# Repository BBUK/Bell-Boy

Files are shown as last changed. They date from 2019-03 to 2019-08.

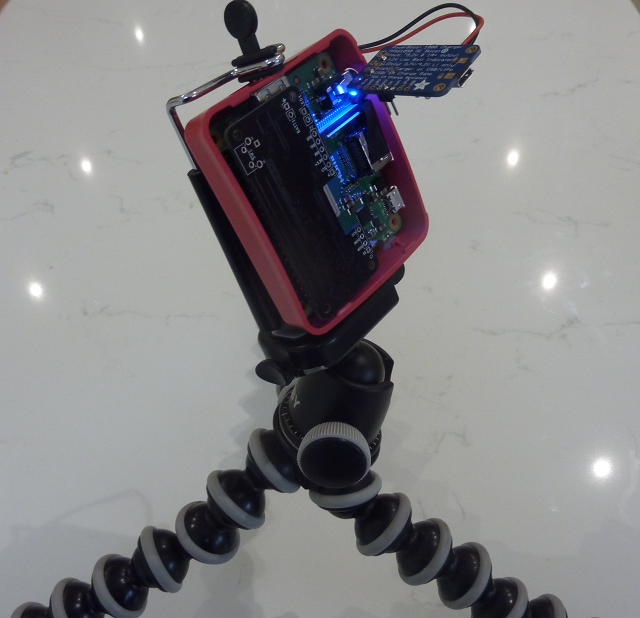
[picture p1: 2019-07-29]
images/CalibrationDevice.png

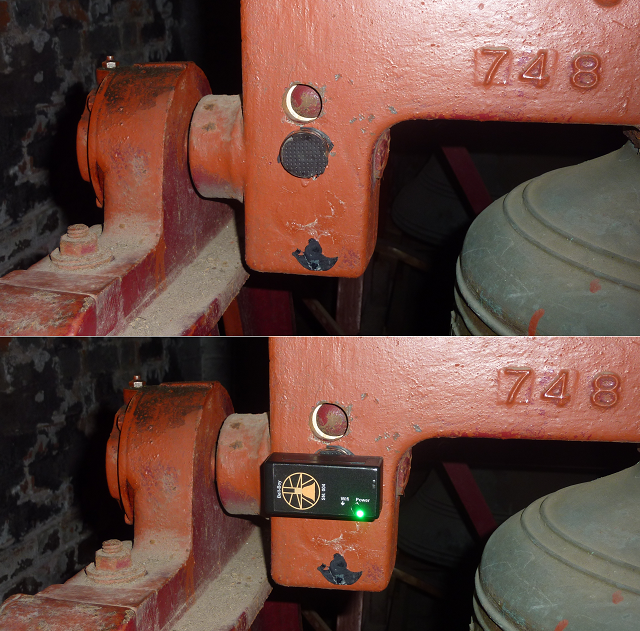
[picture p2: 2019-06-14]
images/Mounting.png

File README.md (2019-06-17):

# Bell-Boy
NEW VERSION IMMINENT - THIS REPOSITORY CONTAINS A GREAT DEAL OF CODE AND INFORMATION IN FLUX BETWEEN VERSIONS SO SHOULD NOT BE RELIED UPON

This repository contains the code and hardware design for the Bell-Boy Project.  

The Bell-Boy is a device used to measure how hard a person pulls on a tower bell rope.  I hope it will be a useful training aid.  

## Hardware

The core of the hardware comprises a Raspberry Pi Zero and a PCB mounted on it containing an IMU IC (an ICM20689), a ATMEGA328 with the Arduino bootloader and power management and battery charging circuitry.  The Arduino manages battery charging, controls a LED and also stores device calibration data.  The battery is a LiPo integral to the device and is charged via power sourced from the Rasperry Pi's micro USB power socket.  The wiki gives construction information if you want to build your own.

The various files and a description of what they do is set out below

This is the second version of the hardware.  The first version was designed to be mounted on top of the headstock.  More accurate measurements were found to have been achieved by mounting the device closer to the gudgeon pins of the bell.  That required the device to be smaller, which required a LiPo battery. As I could not find a case that would fit a Pi0 and one of the AA sized LiPo batteries, a "flat" LiPo was used which then needed associated charging paraphernalia.

Despite only using one consumer-grade IMU, the second version is *much* more accurate than the first.  There is virtually zero drift in angular readings for all three axes (less than 0.3 degrees per hour).  Acceleration measurements are similarly improved.

## Software

### setupBB.sh

This script takes a stock installation of Arch Linux Arm (for the Raspberry Pi) and adds all scripts and installs all required packages to set up the software environment.  See the wiki for more details 

### grabber

This folder contains the source for two small executables.  

The first, "grabber" takes data from the IMU, transforms it into angle, rotational velocity and rotational acceleration and pushes the data to the users browser via a websocket.  As the force applied by the ringer on the rope needs to be distinguished from gravity, vibration and sensor noise, the solution:

(a) oversamples data from the IMUs (sensors output at 500Hz but the user sees 125Hz).

(b) uses a straightforward Mahony-type filter to calculate angles (I previously used the extended Kalman filter (from https://github.com/hhyyti/dcm-imu) to calculate bell angle but it produced no better results in this application).

(c) uses a Savitsky-Golay filter to smooth the measured rotational acceleration

(d) requires an one-time calibration of the IMU system (from https://bitbucket.org/alberto_pretto/imu_tk).  This is a really useful method of scale and bias calibration that does not require the IMU to be exactly positioned.

The grabber communicates with the user's broswer via websocketd (https://github.com/joewalnes/websocketd). 

The second executable "powermonitor" monitors battery level reports from the Arduino and shuts down the Pi if he battery is too low.  It only operates when the grabber is not running (the grabber only runs when there is an active websocket connection to the user's browser - if there is such a connection, the grabber takes over power monitoring).

### bellboy.js

The Javascript that takes the data from the Bell-Boy and presents it to the users browser.  The browser must support HTML5 and websockets.  More details for operation are in the wiki.

### index.html

Index file.  Note that this file and the JS reference certain image files (icons used to control the front end).  These were licensed in my me but whilst I am permitted to include them on websites that I operate or in code that I distribute, I am not permitted to make them available in a separately downloadable form.

### help.html

Help html file served by the Bell-Boy device.

### utility

Some useful utility programs and files.  There is some information here on installing imu_tk (and in particular ceres-solver which is used by imu_tk).

### arduino

Contains the Arduino program running on the "Arduino'd" ATMEGA328 on the Bell-Boy PCB

### old 

Contains some old code and in particular some code for BNO080 interfacing over the Raspberry Pi's SPI which some people may find useful.  I am no longer using the BNO080 so don't expect this code to be updated.

# Donations!
[Donations](https://paypal.me/PBUK) to this project are welcome :)

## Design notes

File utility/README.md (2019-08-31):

## Calibration

Two methods of calibration are provided.  The first uses imu_tk and provides more calibration data (but is difficult to set up) and the second is simpler and can be more easily run on the Bell-Boy itself.

### imu-tk
To calibrate the ICM20689, imu_tk needs to be installed.  imu_tk needs Ceres Solver to be installed.  Ceres Solver only just compiles on the 500MB Pi (better on the larger-memoried models).  Step by step instructions on how to install Ceres Solver and imu_tk are in the NotesOnInstallingimu_tk.txt file.  Other files used are ICM20689.h, BBimu_tk.cpp (a slight variation of the sample file provided as part of imu_tk), calibrate.c and getcalibration.c (the latter is not necessary for doing the calibration but is a handy way of seeing the calibration loaded).

### 6-position
This is in calibrate-6.c.  It is a reasonbly standard 6-position IMU calibration program for 6-DOF IMUs.  This is of the type that uses Gaussian elimination so does not require exact positioning on each of the six faces (within 10 degrees will be fine).  Compile it, run it and as for the imu_tk version, enter SAMP: a few times until you see stable numbers, then enter CALI: to start the calibration process (and follow the on-screen instructions).  Once done, enter SAVE: to save the calibration data to the Bell-Boy.  This program produces good results (pretty much indisguishable from imu_tk in real use) but does not calibrate for gyro scale or axis misalignment errors (which imu_tk does).

## g calculator

gcalculator.xlsx is a little spreadsheet I used to work out what g is in my viscinity.  I am sure the variance in g is not enough to make much difference to results.

## Battery

batteryrecord.txt and BatteryCalibration.xlsx are files file showing how battery voltage is reported over time.  As LiPo batteries discharge on a curve, I could use this data to work out how much battery time is remaining.

## Logo

Bell2LogoSheet.docx is just a Word file with the Bell-Boy logo printed on it (ready to go onto a sticker sheet).

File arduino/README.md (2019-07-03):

## bellboy

This contains an Arduino-style sketch that runs on the ATmega on the Bell-Boy PCB.  The LowPower library is required. 

## BBCalib

A little Arduino sketch that moves servos on my auto calibration deck.

## HotPlate

An Arduino sketch that controls my homebrew soldering hot plate.  It uses a DOGM LCD I had lying around and the PID library.

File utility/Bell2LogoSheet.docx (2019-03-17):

Bell-Boy SN: 001 | UP → | Bell-Boy SN: 002 | UP → | Bell-Boy SN: 003 | UP →
| Wifi Power | | Wifi Power | | Wifi Power
Bell-Boy SN: 004 | UP → | Bell-Boy SN: 005 | UP → | Bell-Boy SN: 006 | UP →
| Wifi Power | | Wifi Power | | Wifi Power
Bell-Boy SN: 007 | UP → | Bell-Boy SN: 008 | UP → | Bell-Boy SN: 009 | UP →
| Wifi Power | | Wifi Power | | Wifi Power
Bell-Boy SN: 010 | UP → | Bell-Boy SN: 011 | UP → | Bell-Boy SN: 012 | UP →
| Wifi Power | | Wifi Power | | Wifi Power
Bell-Boy SN: 013 | UP → | Bell-Boy SN: 014 | UP → | Bell-Boy SN: 015 | UP →
| Wifi Power | | Wifi Power | | Wifi Power
Bell-Boy SN: 016 | UP → | Bell-Boy SN: 017 | UP → | Bell-Boy SN: 018 | UP →
| Wifi Power | | Wifi Power | | Wifi Power
Bell-Boy SN: 019 | UP → | Bell-Boy SN: 020 | UP → | Bell-Boy SN: 021 | UP →
| Wifi Power | | Wifi Power | | Wifi Power
Bell-Boy SN: 022 | UP → | Bell-Boy SN: 023 | UP → | Bell-Boy SN: 024 | UP →
| Wifi Power | | Wifi Power | | Wifi Power
Bell-Boy SN: 025 | UP → | Bell-Boy SN: 026 | UP → | Bell-Boy SN: 027 | UP →
| Wifi Power | | Wifi Power | | Wifi Power

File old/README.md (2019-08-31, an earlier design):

## Here is some old code preserved in case someone finds it useful

### kalman.h

This is a pretty good general Kalman filter for use with 6DOF data.  It produces good results but on testing was not any better than the Mahony filter used as part of the grabber.  It is based on https://github.com/memsindustrygroup/Open-Source-Sensor-Fusion.  It's good for me because it is pure C and does not use anything other than the standard libraries.  Instructions for compilation and use are in the file.

### BNO080grabber.c and BNO080-general.c

I experimented for a bit with the BNO080 devices.  These produced good pose quaternions but tended to recalibrate themselves at inopportune moments.  The two files here are the specific driver for the Bell-Boy grabber and a more general one.

### Other files

Will not be of much use to anyone, except, perhaps the dual MPU6050 code (which I used when the Bell-Boy had two IMU ICs working in parallel.  It demonstrates how I aligned the FIFO outputs from the two ICs.

The 32kHz.c file shows how to create a 32768Hz (ish) clock from the Pi's PWM hardware.  This clock was used for the BNO080s (to save the hardware needing a crystal and a couple of caps).

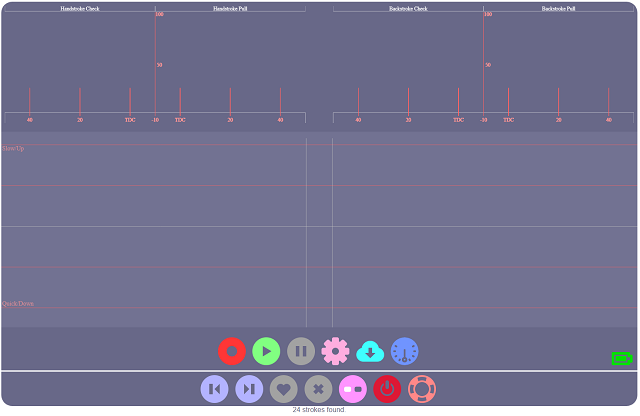
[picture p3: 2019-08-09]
images/FileLoaded.png

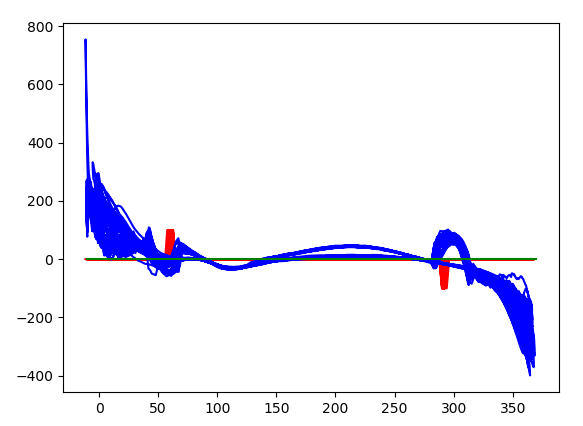
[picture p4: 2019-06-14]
images/OtherEffects2.png

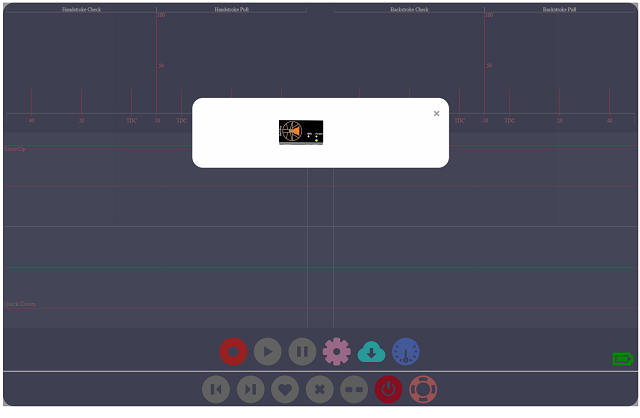
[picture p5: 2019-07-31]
images/EyeCandy.png

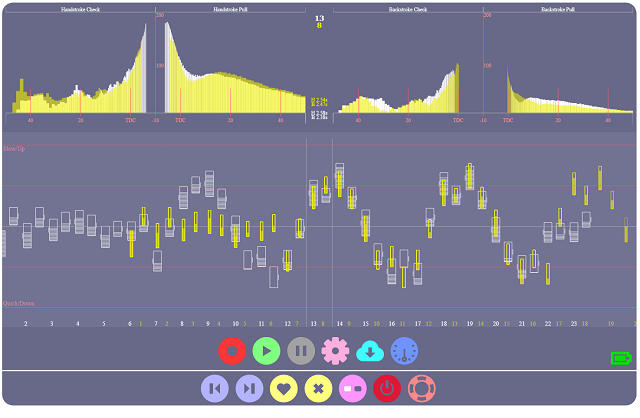
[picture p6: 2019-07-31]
images/StrokeComparison.png

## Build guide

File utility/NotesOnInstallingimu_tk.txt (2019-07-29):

Start with Raspbian full standard installation

sudo apt-get update
sudo apt-get upgrade
sync && sudo reboot
sudo apt-get install build-essential cmake libeigen3-dev libqt4-dev libqt4-opengl-dev freeglut3-dev gnuplot libxmu-dev libxi-dev libgoogle-glog-dev libatlas-base-dev libsuitesparse-dev libboost-dev screen cmake-curses-gui
wget http://ceres-solver.org/ceres-solver-1.14.0.tar.gz
tar xzvf ceres-solver-1.14.0.tar.gz
nano /etc/dphys-swapfile
#change swapfile size to 500. Probably overkill but leave it like this after installation as memory usage for actual calibration runs is huge
sudo systemctl restart dphys-swapfile
mkdir ceres-bin
cd ceres-bin
ccmake ../ceres-solver-1.14.0
# configure
# set build testing to no
# set build examples to no
# configure
# generate
make
#(make will take a long while)
sudo make install

wget https://bitbucket.org/alberto_pretto/imu_tk/get/7780270fb9a2.zip -O imu_tk.zip
unzip imu_tk.zip
cd alberto_pretto-imu_tk-7780270fb9a2/
nano CMakeLists.txt
# add this to the examples section of the file (towards the bottom) (without the hashes)
# add_executable(BBimu_tk apps/BBimu_tk.cpp)
# target_link_libraries( BBimu_tk ${IMU_TK_LIBS})
# set_target_properties( BBimu_tk PROPERTIES RUNTIME_OUTPUT_DIRECTORY ${PROJECT_SOURCE_DIR}/bin)

#copy the BBimu_tk.cpp file to alberto_pretto-imu_tk-7780270fb9a2/apps directory
mkdir build
cd build
cmake ..
### if using gcc version > 6 (eg on Buster), install gcc-6 and g++-6 and run cmake something like this 'cmake -D CMAKE_C_COMPILER="/usr/bin/gcc-6" -D CMAKE_CXX_COMPILER="/usr/bin/g++-6" ..'
make

#install bcm2835 library - see setupBB.sh
#compile calibrate.c needs ICM20689.h
gcc calibrate.c -o calibrate -lbcm2835
# put BBimu_tk (in alberto_pretto-imu_tk-7780270fb9a2/bin) into same directory as calibrate program
# shutdown

## to do a calibration run
# with bellboy PCB installed on header of Pi
# power on system - best to run this after a reboot
# can use battery power if this is running on a zero, if not, power Pi separately and remove battery from bellboy PCB
# run calibrate
# enter SAMP: to get sample period a few times - check numbers are sane and stable (on multiple entries) - near to 0.002 for sample period
# enter CALI: to start calibration run
# keep device stable for at least 50 secs and then move into 20-30 different positions each stable for at least 3-4 seconds(ish)
# ensure that there is a full range of positions (important)
# if EOVF: appears then ctrl-c to exit, reboot and try again
# enter STCA:
# (will now run imu_tk calibration)
# ???high residuals (>2) are an indication that something is not right 
# OK for EOVF: to appear after calibration is finished
# enter SAVE:
# check numbers are sane:
    # all bias numbers close to 0
    # all transform numbers close to 1 on diagonal and close to zero otherwise
# if not sane - ctrl-c to exit within 20 secs. Reboot and try again
# if ctrl-c is not entered, calibration is saved to arduino on bellboy device automatically

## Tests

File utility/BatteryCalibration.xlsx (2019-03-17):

drop: | 0.32
reading: | 447 | voltage: | 4.099865772
 | 459 |  | 4.001045752
 |  |  | #DIV/0!
 |  |  | #DIV/0!
 | 492 |  | 3.754146341
 | 495 |  | 3.733333333
 |  |  | #DIV/0!
 | 498 |  | 3.712771084 | 3.72
 |  |  | #DIV/0!
 |  |  | #DIV/0!
 |  |  | #DIV/0!
 |  |  | #DIV/0!
 |  |  | #DIV/0!
 | 500 |  | 3.6992
 | 506 |  | 3.659130435
 | 509 |  | 3.639449902
 | 511 |  | 3.626457926 | 3.6
 |  |  | #DIV/0!
 |  |  | #DIV/0!
 |  |  | #DIV/0!
 |  |  | #DIV/0!
 |  |  | #DIV/0!
 |  |  | #DIV/0!
 |  |  | #DIV/0!
 |  |  | #DIV/0!
 |  |  | #DIV/0!
 |  |  | #DIV/0!
 |  |  | #DIV/0!
 |  |  | #DIV/0!
 |  |  | #DIV/0!
 |  |  | #DIV/0!
 |  |  | #DIV/0!
 |  |  | #DIV/0!
 | 541 |  | 3.44310536

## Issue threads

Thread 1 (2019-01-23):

BNO080-general.c does not work on my RPi 3B+

tbrych, 2019-01-23:
Hey @BBUK!

I downloaded your code and copied it on my RPi 3B+, after that I installed the BCM2835 lib and compiled your code.
When executing, I get the error "Unsolicited packet not received\n". What does does it mean, that the unsolicited packet wasn't received. This error-message doesn't make any sense to me.
What can I do against it?

The pins connected on the BNO080 are:
PS1 ->   3.3V
GND ->   GND
VDD ->   3.3V
SCK ->   BCM11
SO  ->   BCM9
SI  ->   BCM10
CS  ->   BCM8
WAK ->   BCM25
RST ->   BCM24
INT ->   BCM23

Thank you!
tbrych

BBUK, 2019-01-24:
Hi tbrych.
On reset the BNO080 (should) send a reset packet followed by a long (over 250 byte) unsolicited capability advertisement packet.  The code is complaining that it not seeing the unsolicited packet.  The wiring looks OK,  What BNO080 board are you using?
BBUK

tbrych, 2019-01-25:
We use a Sparkfun BNO080 (https://www.sparkfun.com/products/14686)

BBUK, 2019-01-30:
@tbrych
Weird one.  Worked fine in Arch (which I use).  Tried it in Raspbian (which I assume you are using) and had the same error.

Turned out that the initialisation code did not wait long enough for the unsolicited packet.  I have now pushed a fix but you can just increase the usleep in line 821 from 5000 to 10000.

Thanks for the bug report!  Please report back if this is fixed from your end and I'll close the issue.

tbrych, 2019-02-03:
@BBUK
Thanks for the help, it worked on my side! 👍

BBUK, 2019-02-03:
Thanks for the feedback.  Note that I have just changed the fix slightly to make it more robust.

Closed 2019-02-03.

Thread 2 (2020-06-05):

Issue with BNO080

CalebVaccaro, 2020-06-05:
We are having trouble connecting the I2C with the rPI. We need help with reading data from the sensor from the I2C. Can we pm you?

BBUK, 2020-06-05:
The BNO080 needs I2C clock stretching which the Pi does not do so well.  See here: [https://www.raspberrypi.org/forums/viewtopic.php?t=234577](url) .  This is why I used SPI.  I wonder if this is the problem you are experiencing...

CalebVaccaro, 2020-06-05:
The link is not working. Do you think its still a viable option to use the Pi. We just need quats off the sensor. If not, have you worked with better options for IMUs (components that could accomplish the same goal). Thanks for the reply

Would you know of an SPL library for it?

Parts List:
Qwiic VR IMU (BNO080)
Qwiic pHAT v2.0
Rasberry pi 4

BBUK, 2020-06-05:
Sorry, try this [link](https://www.raspberrypi.org/forums/viewtopic.php?t=234577).  I don't know for sure but I think the Qwiic connectors only use I2C.  I also don't know if the Pi I2C clock stretching bug is still there in the Pi4.

If I2C is a problem then that board can use SPI, you just need to wire the Pi to the SPI pins.  See [issue 1](https://github.com/BBUK/Bell-Boy/issues/1), to see someone who did just that with the same board with success using the code here.

Closed 2020-08-12.

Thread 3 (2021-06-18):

RST in old BNO080-general.c

mdgc3, 2021-06-18:
Good afternoon,
I am fairly new at mechatronics and am working to use SPI with a BNO080. I thought I followed your instructions correctly (yes I tried to make sure I plugged in the correct pins since they are BCM pins), but it keeps getting stuck on "device did not wake on reset". I do not know if it is a wiring issue or because I have a Raspberry Pi 4B and you were using a Raspberry Pi Zero, or if something else is going on. I have attached photos and would really really appreciate some help.
[edit- I saw in your past issues you had a similar question. My wiring is the same I think, but I changed the usleep in line 819 to 10000 just in case. I have also tried plugging in the RST wire on both of the options on the BNO080 from sparkfun]

Below is my wiring: (sorry about color repeats I didn't have a ton of wires)
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

Thank you for your patience,
mdgc3

mdgc3, 2021-07-07:
I seem to have gotten it to work once, but then I upgraded my raspberry pi on the command line and it does not work again.

Also what is a continuation????

BBUK, 2021-07-07:
I see you still have the pull-up resistors connected.  They are only used for i2c.  According to this: https://cdn.sparkfun.com/assets/5/c/c/8/8/SparkFun_Qwiic_VR_IMU_Breakout.pdf the jumper should be cleared (both sides) for SPI usage.  Also, have you set PS0 and PS1 correctly?

mdgc3, 2021-07-07:
I saw you talked about that and eventually cleared the jumper (you mean desoldering the i2c thing, right?).
Also, I soldered the PS0 and PS1 on the other side of the board because the datasheet said they both had to be at 1 to work.

The issue is I downloaded circuitpython to try this SPI communication using that, and it just stopped working again.

Below is a picture of the only time I got it to work

mdgc3, 2021-07-07:
I always get the following response:
"Cannot communicate with BNO080: got 00 DATALENGTH 0001"

I am reading and looking at what u sent me, but I cannot tell what I am doing wrong. This is currently my wiring:
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

BBUK, 2021-07-07:
Are you *sure* that the i2c jumper is cleared?  What you are seeing looks like a bad connection but it could also be caused by the i2c pull-ups.

As a trial, try reducing the speed of the SPI link.  To do that change:
`bcm2835_spi_set_speed_hz(3000000);`
to
`bcm2835_spi_set_speed_hz(1000000);`

mdgc3, 2021-07-07:
Okay so I reconnected all the wires to follow the schematic below:
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

I ran it various times and it said "reset packet not received" each time.
Then I tried changing the line you suggested and then it said "device did not wake on reset" sometimes, but otherwise it is the "reset packet not received"

BBUK, 2021-07-08:
Wiring looks OK.

Try taking the SPI frequency down further:
`bcm2835_spi_set_speed_hz(500000);`
And let me know what you see...

mdgc3, 2021-07-08:
It gave me the same result. I'll check tomorrow if there is still solder on the i2c port. But to confirm, I am not supposed to plug in anything else?

BBUK, 2021-07-08:
Before I try to replicate this, would you please try to add:
`total_mem=1024`
in config.txt (and reboot).  I can see that there is something different in how SPI works on the 4B related to DMA access to higher memory areas (and the bcm2835 library uses DMA, if I recall).

Also check for any SPI-related entries in your config.txt and let me know if there are any there.

mdgc3, 2021-07-09:
Okay I did not know how to make that happen but apparently you can check with "vcgencmd get_config int", and in the photo (below) it says the memory is correct. I did not know how to find the spi info.
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

Also since I was worried it broke due to the circuitpython installation, I tried an extra SD card that had the same formatting as the other one did before. I redownloaded your git and the 1.68 version (newest) version of the BCM library thing. But it did the same "did not wake on reset"/"reset package not received" as usual. So I checked those settings as well.
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

BBUK, 2021-07-09:
Hi again.  I was trying to get you to *reduce* the amount of memory available to your Pi4 on a temporary basis.  To do this you need to edit config.txt (`sudo nano /boot/config.txt`) so that you add the total_mem line.  The end of the file should then look like:

`[pi4]`
`# Enable DRM VC4 V3D driver on top of the dispmanx display stack`
`dtoverlay=vc4-fkms-v3d`
`max_framebuffers=2`
`total_mem=1024`
`[all]`
`# dtoverlay=vc4-fkms-v3d`

I hope you know how to use nano!

mdgc3, 2021-07-09:
Okay so I resoldered the PS1 and PS0 chips. I also removed as much solder as I could on the I2C jumper.
Then I followed your instructions and added the total_mem line but it is still not working :(

BBUK, 2021-07-09:
OK, I will try to replicate here (give me a few days).

While you are waiting - do you have a multimeter? If yes, please would you check the resistance between SO and 3V3 and between SCK and 3V3 (disconnect SO and SCK from the Pi first).

mdgc3, 2021-07-09:
I have a multimeter! And I can check it.
(Is there any chance we can videochat? It might be quicker my email is my github name + @ + gatech.edu)

BBUK, 2021-07-09:
I will have to politely decline the videochat!

Also please do not send me (more) money, this is supposed to be a hobby for me.

mdgc3, 2021-07-09:
That is completely understandable. And yeah that makes sense, I just feel bad wasting your time.

Here is what my multimeter measured.
The 3.3 to SO:
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

The 3.3 to SCK:
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

BBUK, 2021-07-09:
It looks like the SCK side of the i2c solder pads is still connected (probably a tiny solder bridge).  You should be able to see it under a magnifying glass or feel it by running a pin (or something sharp) on each side of the central pad (I don't know without checking which of the two outer pads is connected to SCK.  It is best to use solder wick to clean the bridge (but there are other ways).

mdgc3, 2021-07-09:
Okay I did the solder removing again with the solder wick:
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

Here is a picture of the resistance now:
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

Unfortunately it is still not working :(

mdgc3, 2021-07-09:
In collectPacket(), line 877 seems to be the error. Are lines 861/862 (peri_set_bits) sending packets to the IMU that would cause it to send back a reset signal?

BBUK, 2021-07-09:
collectPacket() could easily act strangely if it is reading junk because other things are not working correctly.

I can see errors in your wiring.  You have connected the chip enable (yellow) to GPIO24 when it should be connected to (physical) PIN24 (marked as CE0 on the Cobbler).  You have connected Wake (white) to GPIO22 when it should be connected to physical PIN22 (which is GPIO25 and marked #25). Also, what have you connected to GPIO18 (physical PIN12) I think you intended to put that into GPIO24 which is physical PIN18 (marked #24 on the cobbler)?  I may not be able to see everything well from the picture so check your wiring carefully - your wiring diagram above is correct (and you shouldn't need to connect PS0/PS1 as long as those pads are solders) - replicate that diagram with the Cobbler and let me know what you see.

If it helps with your wiring see the first image on this page [https://www.raspberrypi.org/documentation/usage/gpio/](url) which shows the differences between GPIO numbers and physical pin numbers.   In my code I use GPIO numbers and the cobbler seems to do the same.

mdgc3, 2021-07-12:
Good morning, I apologize for the delay in response. I was out of town. I did not realize I wired it wrong when I changed into the cobbler but I appreciate it. Now I got it to read!
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
Thank you so much

mdgc3, 2021-07-12:
It was running at 50000, so tired 3000000 and it went poorly, then tried 2000000 and it seems slower but at least doesnt say "cannot communicate with BNO080: got 03 DATALENGTH 0002"

BBUK, 2021-07-12:
Glad to hear that you have it working.

Take the SPI clock rate to as high as it can go whilst working reliably.  You have some pretty long wires there with multiple connections and it is expected that the SPI clock will not be able to operate at the full 3MHz.  2MHz may be too high still (the slowness may simply be a function of only being able to read occasionally).  Try 1.5MHz or even 1MHz.

Also, don't forget to take the `total_mem=1024` line out of config.txt.

BBUK

mdgc3, 2021-07-13:
Thank you so so so much!!!
Yeah it makes sense, I will fiddle with it a bit. Thank you once again!

Closed 2021-07-12.

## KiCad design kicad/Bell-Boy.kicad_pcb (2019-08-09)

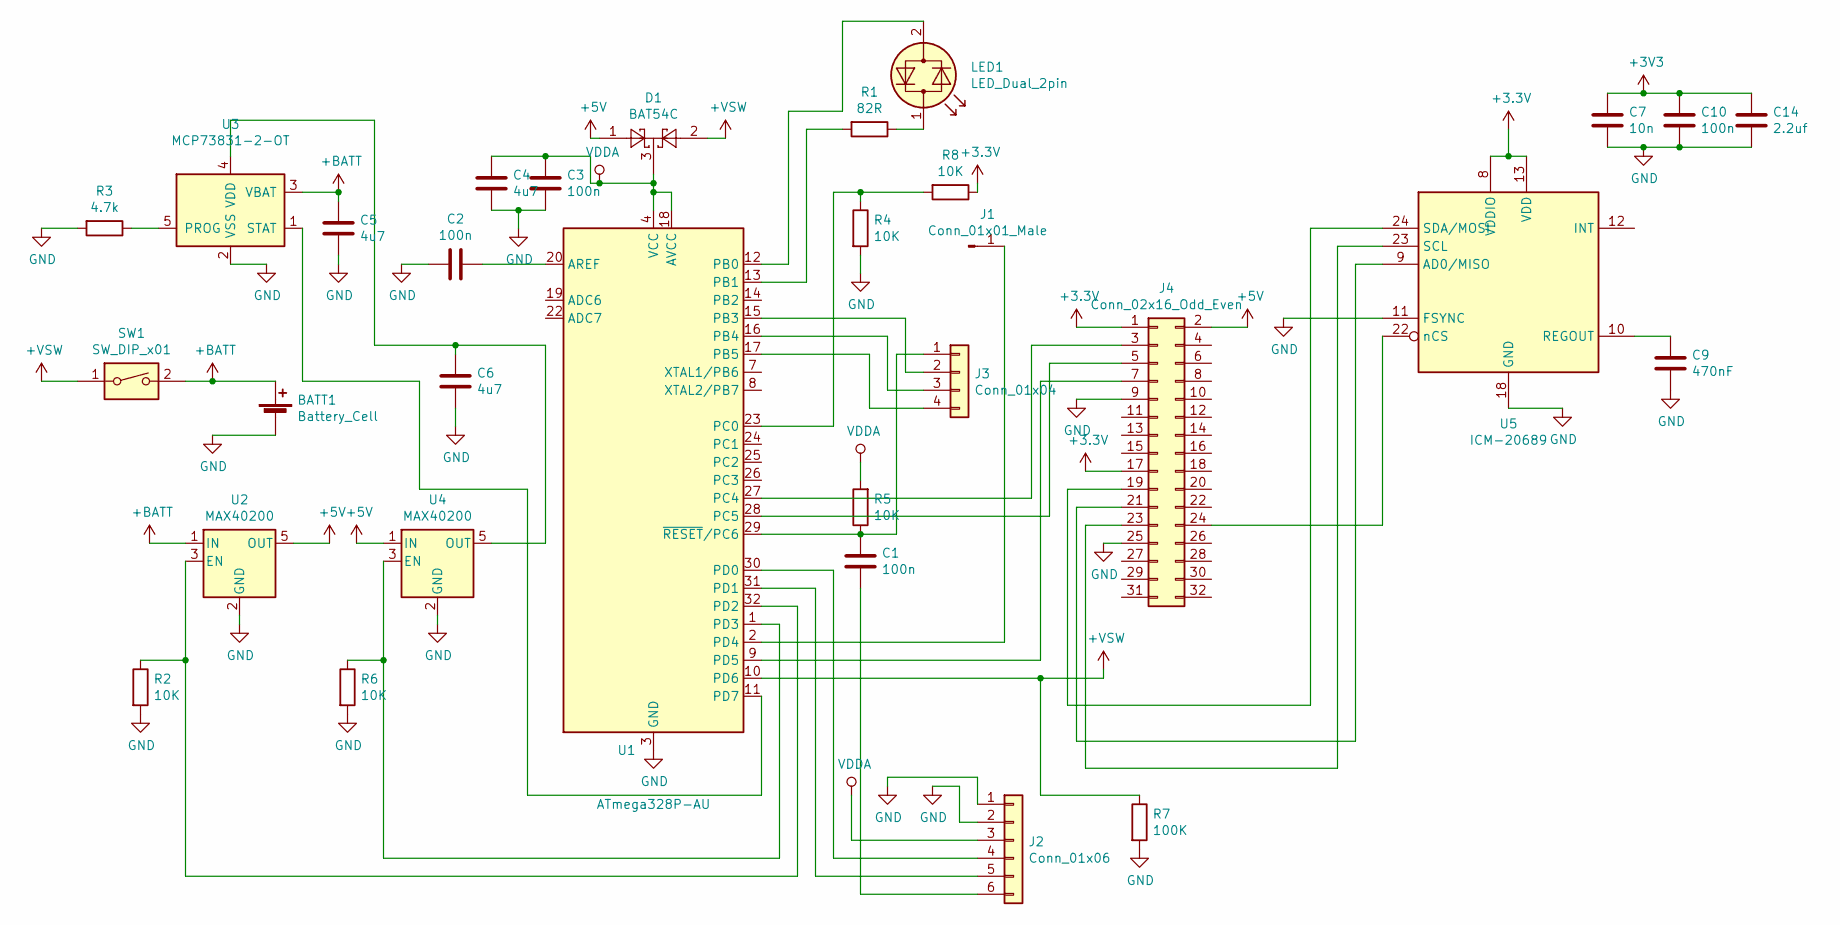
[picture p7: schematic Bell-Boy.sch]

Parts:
BATT1: Battery_Cell; PinHeader_1x02_P2.54mm_Vertical
C1, C2, C3, C10: 100n; C_1206_3216Metric_Pad1.42x1.75mm_HandSolder
C4, C5, C6: 4u7; C_1206_3216Metric_Pad1.42x1.75mm_HandSolder
C7: 10n; C_1206_3216Metric_Pad1.42x1.75mm_HandSolder
C9: 470nF; C_1206_3216Metric_Pad1.42x1.75mm_HandSolder
C14: 2.2uf; C_1206_3216Metric_Pad1.42x1.75mm_HandSolder
D1: BAT54C; SOT-23
J1: Conn_01x01_Male; PinHeader_1x01_P2.54mm_Vertical
J2: Conn_01x06; PinHeader_1x06_P2.54mm_Vertical
J3: Conn_01x04; PinHeader_1x04_P2.54mm_Vertical
J4: Conn_02x16_Odd_Even; PinSocket_2x16_P2.54mm_Vertical_SMD
LED1: LED_Dual_2pin; PinHeader_1x02_P2.54mm_Vertical
R1: 82R; R_1206_3216Metric_Pad1.42x1.75mm_HandSolder
R2, R4, R5, R6, R8: 10K; R_1206_3216Metric_Pad1.42x1.75mm_HandSolder
R3: 4.7k; R_1206_3216Metric_Pad1.42x1.75mm_HandSolder
R7: 100K; R_1206_3216Metric_Pad1.42x1.75mm_HandSolder
SW1: SW_DIP_x01; SW_Tactile_SPST_Angled_PTS645Vx39-2LFS
U1: ATmega328P-AU; LQFP-32_7x7mm_P0.8mm
U2, U4: MAX40200; SOT-23-5
U3: MCP73831-2-OT; SOT-23-5
U5: ICM-20689; InvenSense_QFN-24_4x4mm_P0.5mm

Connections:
+5V: D1.1, J4.2, U2.5 (OUT), U4.1 (IN)
+BATT: BATT1.1 (+), C5.1, SW1.2, U2.1 (IN), U3.3 (VBAT)
+VSW: D1.2, R7.1, SW1.1, U1.10 (PD6)
GND: BATT1.2 (-), C2.2, C3.2, C4.2, C5.2, C6.2, C7.2, C9.2, C10.2, C14.2, J2.1, J2.2, J4.9, J4.25, R2.2, R3.2, R4.2, R6.2, R7.2, U1.3 (GND), U1.5 (GND), U1.21 (GND), U2.2 (GND), U3.2 (VSS), U4.2 (GND), U5.11 (FSYNC), U5.18 (GND)
unnamed: C1.1, J3.1, R5.1, U1.29 (~RESET~/PC6)
unnamed: C1.2, J2.6
unnamed: C2.1, U1.20 (AREF)
unnamed: C6.1, U3.4 (VDD), U4.5 (OUT)
unnamed: C9.1, U5.10 (REGOUT)
unnamed: J1.1, U1.2 (PD4)
unnamed: J2.4, U1.30 (PD0)
unnamed: J2.5, U1.31 (PD1)
unnamed: J3.2, U1.15 (PB3)
unnamed: J3.3, U1.16 (PB4)
unnamed: J3.4, U1.17 (PB5)
unnamed: J4.3, U1.27 (PC4)
unnamed: J4.5, U1.28 (PC5)
unnamed: J4.7, U1.9 (PD5)
unnamed: J4.19, U5.24 (SDA/MOSI)
unnamed: J4.21, U5.9 (AD0/MISO)
unnamed: J4.23, U5.23 (SCL)
unnamed: J4.24, U5.22 (nCS)
unnamed: LED1.1 (KA), R1.1
unnamed: LED1.2 (AK), U1.12 (PB0)
unnamed: R1.2, U1.13 (PB1)
unnamed: R2.1, U1.32 (PD2), U2.3 (EN)
unnamed: R3.1, U3.5 (PROG)
unnamed: R4.1, R8.2, U1.23 (PC0)
unnamed: R6.1, U1.1 (PD3), U4.3 (EN)
unnamed: U1.11 (PD7), U3.1 (STAT)
VDDA: C3.1, C4.1, D1.3, J2.3, R5.2, U1.4 (VCC), U1.6 (VCC), U1.18 (AVCC)

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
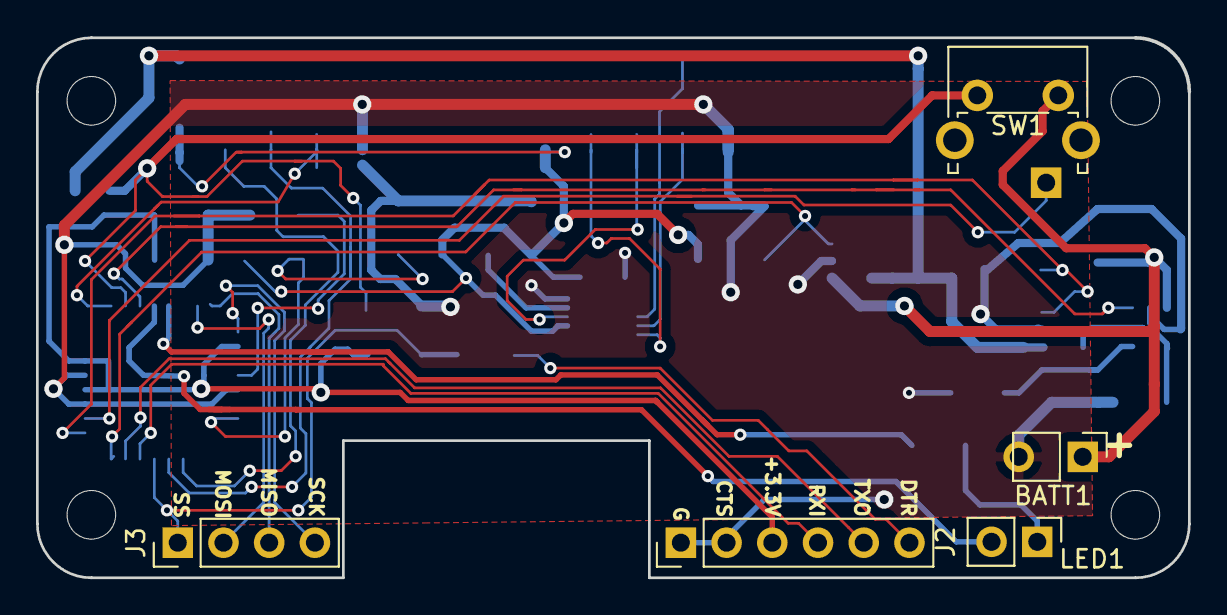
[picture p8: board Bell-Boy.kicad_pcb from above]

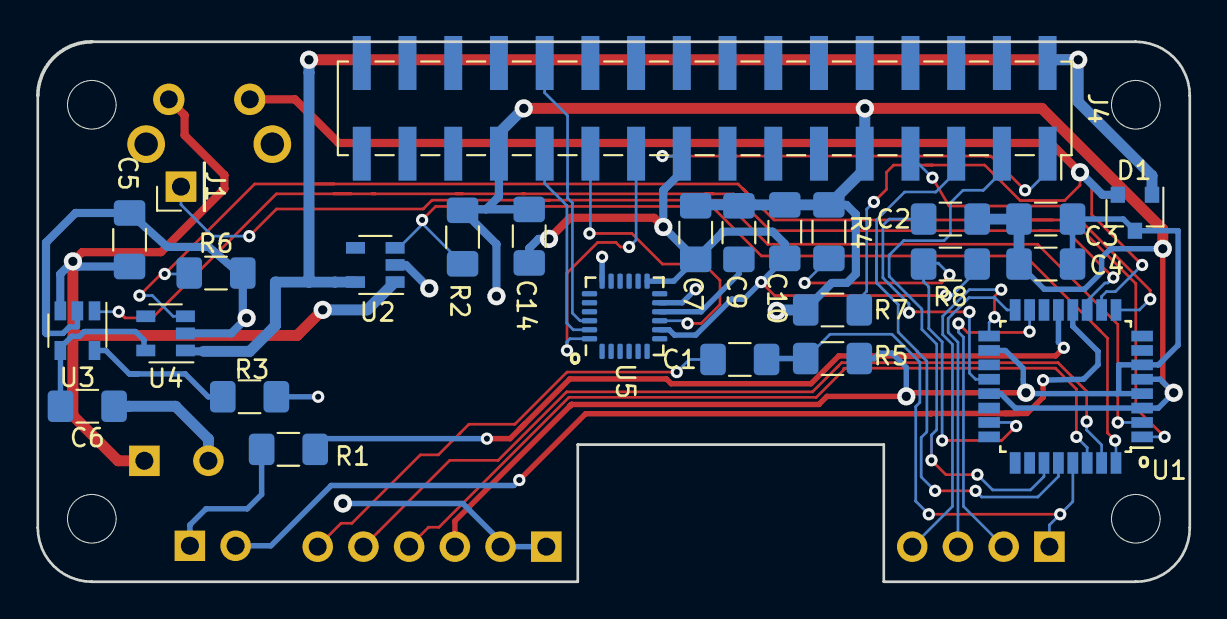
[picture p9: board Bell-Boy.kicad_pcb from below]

Board: 2 copper layers, 64.0 x 30.0 mm, 31 parts (26 on the bottom side), 32 nets.

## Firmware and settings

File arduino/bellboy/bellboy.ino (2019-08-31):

#include "LowPower.h"
#include <Wire.h>
#include <EEPROM.h>

#define piPowerEnablePin 2  // output - enables power to the Pi
#define batteryChargeEnablePin 3 // output enables power to the battery charger
#define piRunPin 4 // output - forces pi not to boot when powered
#define piPowerDownPin 5 // input detects whether Pi is shut down (LOW=UP HIGH=POWERED_DOWN
#define vSwitchDetectPin 6 //input detects status of power button
#define chargeStatusPin 7 // input detects status of battery charge from MCP73831 must be pulled up

uint8_t debounce = 0 ; // debounce count for power button
uint8_t buttonStatus = 0;
#define PRESS 1
#define CHANGED 2

uint8_t promData[5];

volatile uint8_t sleepTime = 0;

volatile float gravityValue = -360.0;
volatile float ropeValueB  = 0.0;
volatile float ropeValueH = 0.0;
volatile float floatW  = -360.0;
volatile float floatX = 0.0;
volatile float floatY = 0.0;
volatile float floatZ = 0.0;

volatile uint8_t LEDcontrol = 0;

union {
  float    _float;
  uint8_t  _bytes[sizeof(float)];
} floatConv;


volatile uint8_t flags = 0;
#define RECEIVEDBOOTUP 1
#define SENDLOWBATT 2
#define WRITETOPROM 4
#define GOTOSLEEP 8

uint8_t loopCount;
volatile float volts = 0;
volatile uint8_t i2cRegister = 0;
volatile char i2cbuffer[12];

// STATE 0 = unknown power source, Pi run pin = low
// STATE 1 = external power source, Pi run pin = low, battery charging
// STATE 2 = external power source, Pi run pin = low, battery charge complete
// STATE 3 = on battery power battery not measured
// STATE 4 = on battery power, battery OK, start booting (flashing red)
// STATE 5 = on battery power, battery OK, Pi booting (flashing green)
// STATE 6 = on battery power, Pi booted (green chirrup)
// STATE 7 = ordered shutdown mode (red flashing)
// STATE 8 = Sleep ordered wait for Pi to shut down
// STATE 9 = Sleep for defined period
// STATE 99 = shut down (rapid red flashing)
volatile uint8_t STATE = 0;
uint8_t count = 0;
void setup() {
  pinMode(8, OUTPUT);
  pinMode(9, OUTPUT);
  ledOff();

  pinMode(piPowerEnablePin, OUTPUT);
  digitalWrite(piPowerEnablePin, LOW);

  pinMode(batteryChargeEnablePin, OUTPUT);
  digitalWrite(batteryChargeEnablePin, LOW);

  pinMode(piRunPin, OUTPUT);
  digitalWrite(piRunPin, LOW); // stop pi running
  Wire.begin(16);
  Wire.setClock(50000);  // set to 50,000 for more reliable comms also on grabber.c, getcalibration.c, powermonitor.c and calibrate.c.  (wire.setclock(50000) will set TWBR to 72 which should work OK).
  Wire.onReceive(i2cReceive);
  Wire.onRequest(i2cPushData);
  ADMUX = _BV(REFS0); // reference to VCC (PC0/ADC0 being measured)
  delay(10);
  volts = measureVcc();
  if (digitalRead(vSwitchDetectPin)) {
    buttonStatus = PRESS;  // stops a long switch on hold switching the thing off immediately
    debounce = 4;
  }
}

void loop() {
  LowPower.idle(SLEEP_500MS, ADC_ON, TIMER2_OFF, TIMER1_OFF, TIMER0_OFF, SPI_OFF, USART0_OFF, TWI_ON);
  if (!(loopCount % 8)) {
    volts = ((3.0 * volts) + measureVcc()) / 4.0;
  }
  loopCount += 1;
  checkSwitch();
  if (flags & WRITETOPROM) writeFloat();

  // (1.65/4.7)*1024 = 359 = connected to external power
  // (1.65/3.9)*1024 = 433 = internal power battery full
  // (1.65/3.2)*1024 = 528 = internal power battery low
  // (1.65/3.1)*1024 = 545 = internal power battery empty
  //                    0 = pi not powered

  switch (STATE) {
    case 0: // startUp
      ledRedOn();
      if (volts < 395 && volts > 200) { // must be on external power
        digitalWrite(batteryChargeEnablePin, HIGH); // enable charging
        pinMode(piRunPin, OUTPUT);
        digitalWrite(piRunPin, LOW); // stop Pi running
        digitalWrite(piPowerEnablePin, HIGH); // need this to ensure arduino will continue to run
        STATE = 1;
      } else {
        digitalWrite(batteryChargeEnablePin, LOW); // disable charging
        digitalWrite(piPowerEnablePin, HIGH); // on battery power, and switch on, send power to Pi
        pinMode(piRunPin, OUTPUT);
        digitalWrite(piRunPin, LOW); // don't allow Pi to run just yet
        delay(100);
        volts = measureVcc(); // remeasure voltage state now Pi is powered
        STATE = 3;
      }
      break;
    case 1: // external power, battery charging
      if (volts > 395) {
        STATE = 99;  // power removed
        break;
      }
      if (digitalRead(chargeStatusPin) == HIGH) {
        STATE = 2;  // charge complete
        digitalWrite(batteryChargeEnablePin, LOW);
        break;
      }
      //      if(flags & RECEIVEDBOOTUP) flags |= SENDLOWBATT; // run header not installed - shut pi down
      ledRedOn();
      break;
    case 2: // external power, charge complete
      if (volts > 395) {
        STATE = 99;  // power removed go into shutdown mode
        break;
      }
      //      if(flags & RECEIVEDBOOTUP) flags |= SENDLOWBATT; // run header not installed - shut pi down
      ledGreenOn();
      break;
    case 3: // battery power,   pi powered, run still low
      if (volts < 520) {
        if (!(buttonStatus & PRESS)) {
          STATE = 4;  // battery OK and button not pressed release run pin
          pinMode(piRunPin, INPUT);
        }
        break;
      } else {
        STATE = 99; // battery not OK, go into shutdown
        break;
      }
    case 4: // battery power, pi powered and running wait for Pi to start booting
      if (digitalRead(piPowerDownPin) == LOW) {
        STATE = 5;  // Pi now booting
        break;
      }
      if (!(loopCount % 2)) {
        ledOff();
      } else {
        ledRedOn();
      }
      if (volts >= 540) { // battery low -> poweroff
        STATE = 99;
      }
      break;
    case 5: // battery power, pi powered and booting, wait for booting to finish
      if (flags & RECEIVEDBOOTUP) {
        STATE = 6;  // Pi now fully up
        break;
      }
      if (!(loopCount % 2)) {
        ledOff();
      } else {
        ledGreenOn();
      }
      if (volts >= 540) { // battery low -> go into order shutdown mode
        flags |= SENDLOWBATT;
        count = 0;
        STATE = 7;
      }
      break;
    case 6: // steady state operation
      if (digitalRead(piPowerDownPin) == HIGH) { // Pi shut itself down
        STATE = 99;
      }
      if (flags & GOTOSLEEP) {
        count = 0;
        STATE = 8;
        flags &= ~GOTOSLEEP;
        flags &= ~RECEIVEDBOOTUP;
      }
      if (volts < 395) { // power plugged in -> go into order shutdown mode
        flags |= SENDLOWBATT;
        count = 0;
        STATE = 7;
      }
      if (volts >= 540) { // battery low -> go into order shutdown mode
        flags |= SENDLOWBATT;
        count = 0;
        STATE = 7;
      }
      if(LEDcontrol == 0){
        if (!(loopCount % 8)) {
          if (volts < 528) {
            ledGreenChirrup();
          } else {
            ledRedChirrup();
          }
        }
      } else {
        if(LEDcontrol == 1 && (loopCount % 2)) ledRedOn();
        if(LEDcontrol == 1 && !(loopCount % 2)) ledGreenOn();
        if(LEDcontrol == 2) ledRedOn();
        if(LEDcontrol == 3) ledGreenOn();
        if(LEDcontrol == 4) ledOff();
      }
      break;
    case 7: // ordered shutdown
      if (digitalRead(piPowerDownPin) == HIGH) { // Pi shut down
        STATE = 99;
        break;
      }
      count++;
      if (count < 150) { // flash red for 75 seconds then force shutdown
        if (!(loopCount % 2)) {
          ledRedOn();
        } else {
          ledOff();
        }
        break;
      } else {
        STATE = 99;
      }
      break;
    case 8: // sleep shutdown ordered
      if (digitalRead(piPowerDownPin) == HIGH) { // Pi shut down
        pinMode(piRunPin, OUTPUT);
        digitalWrite(piRunPin, LOW); // stop Pi running
        ledOff();
        STATE = 9;
        break;
      }
      count++;
      if (count < 150) { // flash green for 75 seconds then force shutdown
        if (!(loopCount % 2)) {
          ledGreenOn();
        } else {
          ledOff();
        }
        break;
      } else {
        pinMode(piRunPin, OUTPUT);
        digitalWrite(piRunPin, LOW); // stop Pi running
        ledOff();
        STATE = 9;
      }
      break;
    case 9: // sleep shutdown
      if (sleepTime == 0) {
        STATE = 0;  // sleepiness has ended let's wake up
        break;
      }
      for (count = 0; count < 198; ++count) { // 30 mins sleep
        LowPower.idle(SLEEP_8S, ADC_ON, TIMER2_OFF, TIMER1_OFF, TIMER0_OFF, SPI_OFF, USART0_OFF, TWI_ON);
        ledRedChirrup();
        delay(50);
        checkSwitch();
        volts = ((3.0 * volts) + measureVcc()) / 4.0;
        if (volts >= 520) {   // low battery - give up on sleep.
            STATE = 99;
        }
        if (volts < 395 && volts > 200){ // plugged in - give up on sleep and start charging
            gravityValue = -360.0;
            ropeValueH = 0.0;
            ropeValueB = 0.0;
            floatW  = -360.0;
            floatX = 0.0;
            floatY = 0.0;
            floatZ = 0.0;
            STATE = 0;
        }
        if(STATE !=9) break;
      }
      sleepTime -= 1;
      break;
    case 99: // shutdown
      for (uint8_t j = 0; j < 10; j++) {
        ledRedOn();
        delay(50);
        ledOff();
        delay(50);
      }
      digitalWrite(batteryChargeEnablePin, LOW);
      pinMode(piRunPin, OUTPUT);
      digitalWrite(piRunPin, LOW);
      digitalWrite(piPowerEnablePin, LOW);
      LowPower.powerDown(SLEEP_FOREVER, ADC_OFF, BOD_OFF);
  }
}

void checkSwitch(void){
  if (digitalRead(vSwitchDetectPin)) {
    if (debounce != 5) debounce += 1;
  } else {
    if (debounce != 0) debounce -= 1;
  }
  if ((debounce >= 3) && !(buttonStatus & PRESS)) buttonStatus = PRESS | CHANGED; // was off now on, so switch on and flag (bit 2)
  if ((debounce < 2 ) && (buttonStatus & PRESS)) buttonStatus = CHANGED; // was on now off, so switch on and flag (bit 2)

  if (buttonStatus & CHANGED) {
    buttonStatus &= ~CHANGED;  // switch off change flag
    if (buttonStatus & PRESS) {
      if (STATE == 1 || STATE == 2 || STATE == 4 || STATE == 7 || STATE == 8 || STATE == 9) STATE = 99; // power button forces shutdown
      if (STATE == 5 || STATE == 6) { // go into order shutdown mode
        flags |= SENDLOWBATT;
        count = 0;
        STATE = 7;
      }
    }
  }
}

void writeFloat(void) {
  EEPROM.write(promData[0] << 2, promData[1]);
  EEPROM.write((promData[0] << 2) + 1, promData[2]);
  EEPROM.write((promData[0] << 2) + 2, promData[3]);
  EEPROM.write((promData[0] << 2) + 3, promData[4]);
  flags &= ~WRITETOPROM;
}

void i2cReceive(int number) {
  i2cRegister = Wire.read();
  if (i2cRegister == 1) flags |= RECEIVEDBOOTUP;
  if (i2cRegister >= 10 && i2cRegister <= 34 && number == 5 && !(flags & WRITETOPROM)) { // got an PROM write COMMAND
    promData[0] = i2cRegister;
    promData[1] = Wire.read();
    promData[2] = Wire.read();
    promData[3] = Wire.read();
    promData[4] = Wire.read();
    flags |= WRITETOPROM;
  }

  if (i2cRegister == 2 && number == 2) { // got a sleep command
    sleepTime = Wire.read();
    flags |= GOTOSLEEP;
  }

  if (i2cRegister == 3 && number == 5) { // read floatW
    floatConv._bytes[0] = Wire.read();
    floatConv._bytes[1] = Wire.read();
    floatConv._bytes[2] = Wire.read();
    floatConv._bytes[3] = Wire.read();
    floatW = floatConv._float;
  }

  if (i2cRegister == 4 && number == 5) { // read floatX
    floatConv._bytes[0] = Wire.read();
    floatConv._bytes[1] = Wire.read();
    floatConv._bytes[2] = Wire.read();
    floatConv._bytes[3] = Wire.read();
    floatX = floatConv._float;
  }

  if (i2cRegister == 5 && number == 5) { // read floatY
    floatConv._bytes[0] = Wire.read();
    floatConv._bytes[1] = Wire.read();
    floatConv._bytes[2] = Wire.read();
    floatConv._bytes[3] = Wire.read();
    floatY = floatConv._float;
  }

  if (i2cRegister == 6 && number == 5) { // read floatZ
    floatConv._bytes[0] = Wire.read();
    floatConv._bytes[1] = Wire.read();
    floatConv._bytes[2] = Wire.read();
    floatConv._bytes[3] = Wire.read();
    floatZ = floatConv._float;
  }

  if (i2cRegister == 7 && number == 5) { // read rope value
    floatConv._bytes[0] = Wire.read();
    floatConv._bytes[1] = Wire.read();
    floatConv._bytes[2] = Wire.read();
    floatConv._bytes[3] = Wire.read();
    ropeValueH = floatConv._float;
  }

  if (i2cRegister == 8 && number == 5) { // read rope value
    floatConv._bytes[0] = Wire.read();
    floatConv._bytes[1] = Wire.read();
    floatConv._bytes[2] = Wire.read();
    floatConv._bytes[3] = Wire.read();
    ropeValueB = floatConv._float;
  }

  if (i2cRegister == 9 && number == 5) { // read gravity value
    floatConv._bytes[0] = Wire.read();
    floatConv._bytes[1] = Wire.read();
    floatConv._bytes[2] = Wire.read();
    floatConv._bytes[3] = Wire.read();
    gravityValue = floatConv._float;
  }
  if (i2cRegister == 50 && number == 2) { // got manual LED command
    LEDcontrol = Wire.read();
  }
}

/*
    (registers   10=samplePeriod, 11=accBiasX,
    12=accBiasY, 13=accBiasZ, 14=accScale00, 15=accScale01, 16=accScale02,
    17=accScale10, 18=accScale11, 19=accScale12, 20=accScale20, 21=gyroScale21,
    22=accScale22, 23=gyroBiasX, 24=gyroBiasY, 25=gyroBiasZ, 26=gyroScale00,
    27=gyroScale01, 28=gyroScale02, 29=gyroScale10, 30=gyroScale11, 31=gyroScale12,
    32=gyroScale20, 33=gyroScale21, 34=gyroScale22,
    200=accBiasXYZ(all in one go 12 bytes, three floats),
    201=accScale0(all in one go 12 bytes, three floats),
    202=accScale1 (all in one go 12 bytes, three floats),
    203=accScale2 (all in one go 12 bytes, three floats),
    204=gyroBiasXYZ(all in one go 12 bytes, three floats),
    205=gyroScale0(all in one go 12 bytes, three floats),
    206=gyroScale1 (all in one go 12 bytes, three floats),
    207=gyroScale2 (all in one go 12 bytes, three floats).
*/

void i2cPushData() {
  uint16_t iVolts;
  if (i2cRegister == 2) { // send voltage
    iVolts = (uint16_t)(volts + 0.5);
    if (flags & SENDLOWBATT) iVolts += 0x8000;
    i2cbuffer[0] = iVolts >> 8;
    i2cbuffer[1] = iVolts & 0x00FF;
    Wire.write((char *)i2cbuffer, 2);
  } else if (i2cRegister == 3) { // send floatW
    floatConv._float = floatW;
    Wire.write((char *)floatConv._bytes, 4);
  } else if (i2cRegister == 4) {
    floatConv._float = floatX;
    Wire.write((char *)floatConv._bytes, 4);
  } else if (i2cRegister == 5) {
    floatConv._float = floatY;
    Wire.write((char *)floatConv._bytes, 4);
  } else if (i2cRegister == 6) {
    floatConv._float = floatZ;
    Wire.write((char *)floatConv._bytes, 4);
  } else if (i2cRegister == 7) { // send rope data
    floatConv._float = ropeValueH;
    Wire.write((char *)floatConv._bytes, 4);
  } else if (i2cRegister == 8) { // send rope data
    floatConv._float = ropeValueB;
    Wire.write((char *)floatConv._bytes, 4);
  } else if (i2cRegister == 9) { // send gravity data
    floatConv._float = gravityValue;
    Wire.write((char *)floatConv._bytes, 4);
  } else if (i2cRegister >= 10 && i2cRegister <= 34) { // send EEPROM data
    i2cbuffer[0] = EEPROM.read(i2cRegister << 2);
    i2cbuffer[1] = EEPROM.read((i2cRegister << 2) + 1);
    i2cbuffer[2] = EEPROM.read((i2cRegister << 2) + 2);
    i2cbuffer[3] = EEPROM.read((i2cRegister << 2) + 3);
    Wire.write((char *)i2cbuffer, 4);
  } else if (i2cRegister == 200) { // send accBiasXYZ
    populateBuffer(44);
    Wire.write((char *)i2cbuffer, 12);
  } else if (i2cRegister == 201) { // send accScale0
    populateBuffer(56);
    Wire.write((char *)i2cbuffer, 12);
  } else if (i2cRegister == 202) { // send accScale1
    populateBuffer(68);
    Wire.write((char *)i2cbuffer, 12);
  } else if (i2cRegister == 203) { // send accScale2
    populateBuffer(80);
    Wire.write((char *)i2cbuffer, 12);
  } else if (i2cRegister == 204) { // send gyroBiasXYZ
    populateBuffer(92);
    Wire.write((char *)i2cbuffer, 12);
  } else if (i2cRegister == 205) { // send gyroScale0
    populateBuffer(104);
    Wire.write((char *)i2cbuffer, 12);
  } else if (i2cRegister == 206) { // send gyroScale1
    populateBuffer(116);
    Wire.write((char *)i2cbuffer, 12);
  } else if (i2cRegister == 207) { // send gyroScale2
    populateBuffer(128);
    Wire.write((char *)i2cbuffer, 12);
  } else {
    Wire.write(99);
  }
}

void populateBuffer(uint8_t reg) {
  i2cbuffer[0] = EEPROM.read(reg);
  i2cbuffer[1] = EEPROM.read(reg + 1);
  i2cbuffer[2] = EEPROM.read(reg + 2);
  i2cbuffer[3] = EEPROM.read(reg + 3);
  i2cbuffer[4] = EEPROM.read(reg + 4);
  i2cbuffer[5] = EEPROM.read(reg + 5);
  i2cbuffer[6] = EEPROM.read(reg + 6);
  i2cbuffer[7] = EEPROM.read(reg + 7);
  i2cbuffer[8] = EEPROM.read(reg + 8);
  i2cbuffer[9] = EEPROM.read(reg + 9);
  i2cbuffer[10] = EEPROM.read(reg + 10);
  i2cbuffer[11] = EEPROM.read(reg + 11);
}

// (1.65/5.0)*1024 = 338 = connected to external power
// (1.65/4.2)*1024 = 402 = internal power battery full
// (1.65/3.5)*1024 = 482 = internal power battery low
// (1.65/3.4)*1024 = 496 = internal power battery empty
//                     0 = pi not powered

uint16_t measureVcc(void) {
  uint8_t low;
  //    LowPower.adcNoiseReduction(SLEEP_15MS, ADC_ON, TIMER2_ON);
  ADCSRA |= _BV(ADSC);
  while (bit_is_set(ADCSRA, ADSC));
  low  = ADCL;
  return (ADCH << 8) | low;
}

void ledRedOn(void) {
  digitalWrite(8, LOW);
  digitalWrite(9, HIGH);
}

void ledGreenOn(void) {
  digitalWrite(8, HIGH);
  digitalWrite(9, LOW);
}

void ledOff(void) {
  digitalWrite(8, LOW);
  digitalWrite(9, LOW);
}

void ledYellow(void) {
  for (uint8_t i = 0; i < 25; ++i) {
    digitalWrite(8, LOW);
    digitalWrite(9, HIGH);
    delay(10);
    digitalWrite(8, HIGH);
    digitalWrite(9, LOW);
    delay(5);
  }
}

void ledRedChirrup(void) {
  ledRedOn();
  LowPower.idle(SLEEP_15MS, ADC_ON, TIMER2_OFF, TIMER1_OFF, TIMER0_OFF, SPI_OFF, USART0_OFF, TWI_ON);
  ledOff();
}

void ledGreenChirrup(void) {
  ledGreenOn();
  LowPower.idle(SLEEP_30MS, ADC_ON, TIMER2_OFF, TIMER1_OFF, TIMER0_OFF, SPI_OFF, USART0_OFF, TWI_ON);
  ledOff();
}

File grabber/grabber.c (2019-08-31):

//gcc grabber.c -o grabber -lm -lbcm2835 -Wall -O3

/*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
* This program forms part of the Bell-Boy project to measure the force applied by a bell ringer to a tower
* bell rope.  The Bell-Boy uses rotational acceleration of the bell as a proxy for force applied.  The
* hardware is currently a Pi Zero running Arch Linux.
*
* The results of the "engineering" and "experimentation" work on the bell system are described here.
* Although it will work straight from the command line, this program is intended to be started 
* by Websocketd https://github.com/joewalnes/websocketd
* On startup, it initialises the IMU (setup() function which, checks if the device is already calibrated by checking
* the getSavedSata() function and checking if the device has awoken from sleep) and the main loop is entered. 
* The main loop starts calling doCalibration() if the device is uncalibrated and pushData() if it is.
* If uncalibrated, there is first a zero calibration (needs about 30 seconds of stability to bias-adjust the gyros and to zero
* the bell position (this is done by the pullAndTransform() function, called by doCalibration()). After zeroing, 
* the user is invited to pull up and set the bell.  Once the bell is set the user is invited to start ringing a few times.
* One the bell is being rung full circle, doCalibration() starts saving data. Once the bell has gone through the calibration 
* routine, doCalibration() calculates the effect of gravity and the rope on the bell.  See calculateError() and calculateArea(). 
* Once this calibration is complete pushData() is called in the main loop.  pushData() calls populateBuffer() 
* which takes data from the IMU and converts it to calibrated orientation and rotational velocity.
* Although this data is not pushed to the browser until the user signals that they want to record a run, 
* the data is always processed as it allows for some gyro calibration (pullAndTransform() function) and for the filters to settle down.
*  
* The main loop:
*       *  checks the Arduino for battery life and reports this to the browser
*       *  checks stdin for commands from the browser (see below) and processes these commands
*       *  calls doCalibration() if device has not yet been calibrated on the bell and pushData() otherwise
* setup:
*       * called pre-main loop
*       * configures the IMU device over SPI
*       * checks to see if device has woken from sleep and, if so, collects calibration data from Arduino
*       * pulls calibration data from the Arduino over I2C
* doCalibration
*       * follows a multi-step calibration process
*       * bell-down and stable for around 30 seconds to remove gyro biasses and to get BDC adjustment (grabberData.tare quaternion)
*       * bell is rung up and set
*       * bell is then rung full circle (at least 5 full strokes 10 strikes), data is collected
*       * data is processed to calculate calibration values (principally gravityValue)
* pushData
*       * calls populateBuffer()
*       * pushes angle, rate and acceleration to the browser
*       * also calls dingDong() which checks to see if a strike needs to be recorded
* populateBuffer is called by pushData
*       * checks to see if enough data is in the two IMUs' FIFOs to be pulled and processed
*       * calls pullAndTransform to actually pull the data and process it into angles
*       * puts processed data (angle, angular rate and acceleration) into a circular buffer
*       * acceleration is calculated using a Savitsky-Golay filter ( savGol() )
* savgol
*       * processes angular rate data to create angular acceleration data
* dingDong
*       * checks to see if we are in faked strike mode (tied clappers) and, if we are, reports strike at
*       * the appropriate time
*       * if not in faked strike mode, double differentiates angular velocity data (slightly smoothed)
*       * using a Savitsky-Golay filter (a different one to that used by SavGol() )
*       * and checks for a big increase in rate of acceleration of bell and takes that as a strike
*       * assumes bell strikes at the same angle (appears to be true) and averages results of detected
*       * strikes using a complementary filter (averaging not really necessary but guards against
*       * possible non-detection)
* pullAndTransform
*       * called by pullData and by doCalibration(), takes data from the IMU (over SPI) and then 
*       * adjusts for bias, scale and misalignment, checks to see if the bell has been stationary 
*       * for a while and if it has it takes the opportunity to recalculate the gyro biasses
*       * calls calculate() function to update rotation quaternion and Euler angles
* calculate
*       * called by pullAndTransform()
*       * uses the well-known Mahony complementary filter as written in quaternion form by Madgwick
* startRun
*       * called when the user has indicated that a recording should be started
*       * works out which way the bell went up (the device can be mounted either side of the headstock)
*       * initialises the circular buffer
*       * sets the RUNNING global to true (signals to pushData() that data can be pushed to browser) 
* 
* There are the following possible command sent by the user's browser.  
* Commands are received on stdin and output is on stdout (which is what Websocketd expects):
* (a)   STRT:[filename] Start recording a session with a bell.  The bell
*       must be at stand and (reasonably) stationary otherwise this
*       will return ESTD: or EMOV: either of which signals the browser 
*       to stop expecting data.  If Filename is not provided then a
*       default filename of "Unnamed_[date]" is used.
* (b)   STOP: stops a recording in progress.  This also saves off the
*       collected data into the relevant file in /data/samples/
* (c)   LDAT: a request for data from the browser, only works when there
*       is a recording in progress - deprecated.  Does nothing.
* (d)   FILE: get a listing of the previous recordings stored in
*       /data/samples/ .  Used to display the selection box to the user.
* (e)   LOAD:[filename] used to transmit a previous recording to the browser
* (f)   DATE:[string] sets the date on the device to the date on the browser 
*             string is unixtime (microsecs since 1/1/70)
* (g)   SAMP: requests the current sample period
* (h)   SHDN: tells the device to shutdown
* (i)   EYEC: starts eye candy demo
* (j)   STEC: stops eye candy demo
* (k)   STND: standalone (playback-only) operation.
* (l)   PLRD: play and record operation.
* (m)   BELS: bell data. Format: numberofbells(int),CPM(float),openHandstroke(float), manualtimefromBDC(float)
* (o)   SLEP:[number] go to sleep for [number] of half hour units.
* (p)   MAXF: requests maximum amount of samples held on on-chip FIFO buffer - for testing higer sample rates
*
* There are the following responses back to the user's browser:
* (i)    STPD: tells the browser that the device has sucessfully stopped sampling
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

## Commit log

2017-07-07 Formatting, correcting gyro
2017-07-09 Fixed gyro scaling
2017-07-10 Correct sign of a(tang)
    [bell_boy_wsh.py]
2017-07-26 Added gyro only test
2018-01-29 Further updates and fixes
    [osh-park_2_layer_standard_order.kicad_pcb, osh-park_2_layer_standard_order.sch]
2018-01-31 Implement gyro bias
2018-02-03 Uploaded PCB files
    [Bell-Boy-B.Cu.gbr, Bell-Boy-B.Mask.gbr, Bell-Boy-B.SilkS.gbr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]
2018-02-06 Add calibration system
2018-02-09 Bugfix - angle_correction not to be preserved across sessions
    [bb_dcmimu.c]
2018-02-10 Finalised(ish) calibration
2018-02-11 New calibration method
2018-02-13 PCB and other updates
    [Bell-Boy-B.Cu.gbr, Bell-Boy-B.Mask.gbr, Bell-Boy-B.SilkS.gbr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]
2018-02-25 New overlay method (ex timers)...
2018-02-25 New overlay method (ex timers and images)...
2018-03-06 Added MPU6050 dual IMU code
2018-03-16 Automated all calibration. Updated PCB
    [Bell-Boy-B.Cu.gbr, Bell-Boy-B.Mask.gbr, Bell-Boy-B.SilkS.gbr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]
2018-03-18 Wifi fix, images, simplify local
    [grabber.c]
2018-03-27 PCB update and tidy-ups
    [Bell-Boy-B.Cu.gbr, Bell-Boy-B.Mask.gbr, Bell-Boy-B.SilkS.gbr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]
2018-08-27 Side mounting
2018-10-09 BNO080 trial and minor fix
    [BNO080.h]
2018-12-04 Update 400Hz
2019-01-06 Introduced Savitzky–Golay filter and other changes
2019-01-15 Updater completed. Added Arduino file
2019-02-21 Updates to new case format
    [Bell-Boy-B.Mask.gbr, Bell-Boy-B.Paste.gbr, Bell-Boy-B.SilkS.gbr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]
2019-03-17 Major updates to ICM20689 and fixes
    [BatteryCalibration.xlsx, gcalculator.xlsx]
2019-03-17 Calibration setup and fixes
    [bellboy.ino, calibrate.c, grabber.c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]
2019-03-17 Update PCB files
    [Bell-Boy-B.Cu.gbr, Bell-Boy-B.Mask.gbr, Bell-Boy-B.Paste.gbr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]
2019-03-18 Tidy ups
    [Bell-Boy-B.Cu.gbr, Bell-Boy-B.Mask.gbr, Bell-Boy-B.Paste.gbr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]
2019-03-18 Repushed Kicad files
    [Bell-Boy-B.Cu.gbr, Bell-Boy-B.Mask.gbr, Bell-Boy-B.Paste.gbr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]
2019-03-20 Made calibration more robust against overflows
2019-03-30 Updates to calibration
2019-03-31 Calibration improvements. Eye candy now uses quaternion. Commit to Mahony filter.
2019-04-06 Fixed yukky interaction between powermonitor and grabber (and race condition)
    [grabber.c, powermonitor.c]
2019-04-15 Bug fix for calibrate function.
    [grabber.c]
2019-04-22 Start updates to single IMU
2019-04-28 Finished autotare and single IMU conversion
    [Bell-Boy-B.Cu.gbr, Bell-Boy-B.Mask.gbr, Bell-Boy-B.Paste.gbr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]
2019-05-19 Partial completion of ding dong detector and movement of gravity calibration to device. Removed dcm_imu.
2019-07-03 Correcting all the errors I made when rebasing to 500Hz(!). Slight benefit in having -03 compile optimisation. Updated FirstSample to new format. Added hotplate sketch.
    [HotPlate.ino, bellboy.ino, grabber.c]
2019-07-04 Tested calibration process on Buster/Pi4
2019-07-05 Changed SavGol filter length after testing at 500Hz. Minor bug fix.
    [grabber.c]
2019-07-13 Some code rejigging. Rope effect calibration for testing.
2019-07-27 PCB updates, scales now easier to read
    [Bell-Boy-B.Cu.gbr, Bell-Boy-B.Mask.gbr, Bell-Boy-B.Paste.gbr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]
2019-07-29 Made calibration more robust against overflows.
2019-08-09 Minor updates
    [Bell-Boy-B.Cu.gbr, Bell-Boy-B.Mask.gbr, Bell-Boy-B.Paste.gbr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]
2019-08-20 Corrected a couple of errors in last commit, introduced Kalman filter for testing
    [grabber.c, kalman.h]
2019-08-25 Added simpler calibration option.
2019-08-31 Retired Kalman filter. More quaternion rotation stuff.

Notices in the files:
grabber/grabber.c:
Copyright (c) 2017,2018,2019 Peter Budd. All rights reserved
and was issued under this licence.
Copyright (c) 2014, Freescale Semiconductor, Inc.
